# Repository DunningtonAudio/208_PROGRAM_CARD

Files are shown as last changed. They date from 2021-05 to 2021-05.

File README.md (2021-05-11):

# 208_PROGRAM_CARD
A 208 program card project

These Model 208 Program Cards are designed to interface with the “PROGRAM BOARD” edge connector of a Buchla & Associates Model 208 Stored Program Sound Source module and its reissues / compatible units. Two versions are provided, one for standard use and one with a prototyping area where additional active circuitry can be added if desired. For guidance on general use, see Allen Strange’s “Programming and Meta-Programming the Electro Organism” manual.

Beyond the settings / connections available on the original cards, the following features are provided:

* A label area on the rear of the card for easy identification of presets.
* Modulation oscillator range switch setting (where this is available on the 208 edge connector).
* An extra connection point for each of the random voltage outputs.
* Footprints for optional multi-turn trimmer potentiometers (Bourns 3266W type) in series with the sequencer voltage level settings for fine tune when programming pitched sequences.
* 5V rail brought out to the prototyping area (where this is available on the 208 edge connector)

Please read the notes before ordering or using cards.

The repository contains:

* KiCad project files, including gerber outputs
* Schematic, notes and 208 manual as PDF files

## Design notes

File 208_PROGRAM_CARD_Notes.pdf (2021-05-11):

208 Program Cards

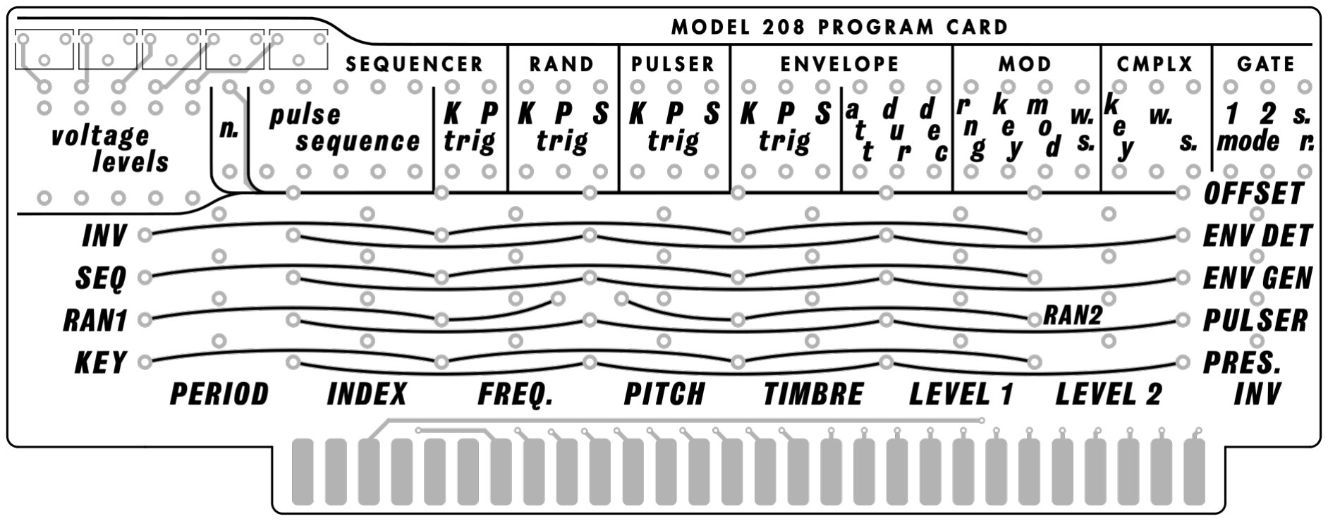
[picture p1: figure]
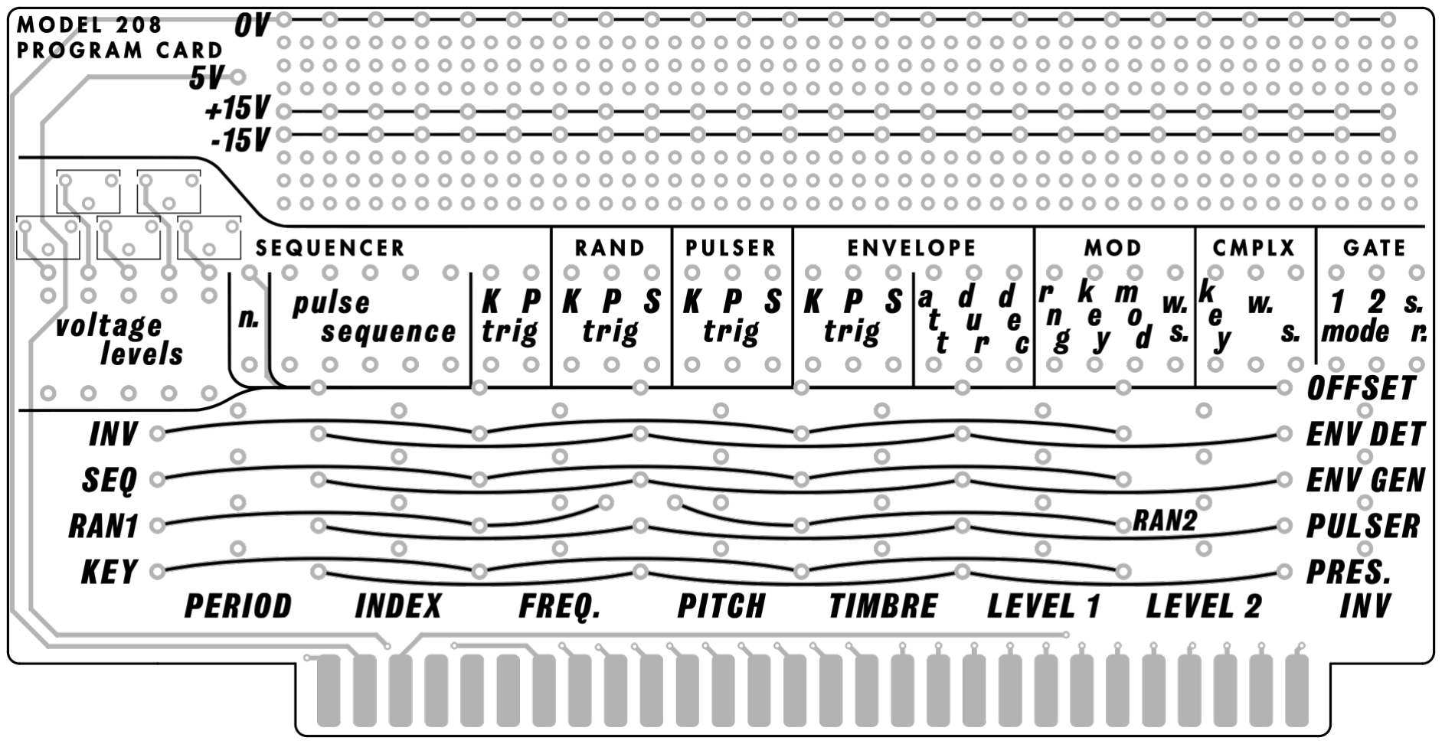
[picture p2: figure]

These Model 208 Program Cards are designed to interface with the “PROGRAM BOARD” edge connector of a Buchla & Associates Model 208 Stored Program Sound Source module and its reissues / compatible units. Two versions are provided, one for standard use and one with a prototyping area where additional active circuitry can be added if desired. For guidance on general use, see Allen Strange’s “Programming and Meta-Programming the Electro Organism” manual.

PLEASE NOTE:

**Inserting / removing program cards whilst the 208 is powered is not recommended or supported**

**The system power rails are exposed in the prototype area – use with caution to avoid damage to the power supply or 208 module**

**Not all functions provided on the cards are available on all 208 type modules**

**These cards are not compatible with Roman Filippov’s 208r rev 1**

Beyond the settings / connections available on the original cards, the following features are provided:

- A label area on the rear of the card for easy identification of presets.
- Modulation oscillator range switch setting (where this is available on the 208 edge connector).
- An extra connection point for each of the random voltage outputs.
- Footprints for optional multi-turn trimmer potentiometers (Bourns 3266W type) in series with the sequencer voltage level settings for fine tune when programming pitched sequences. Depending on whether a trimmer will be fitted, solder fixed resistors between the pads indicated:

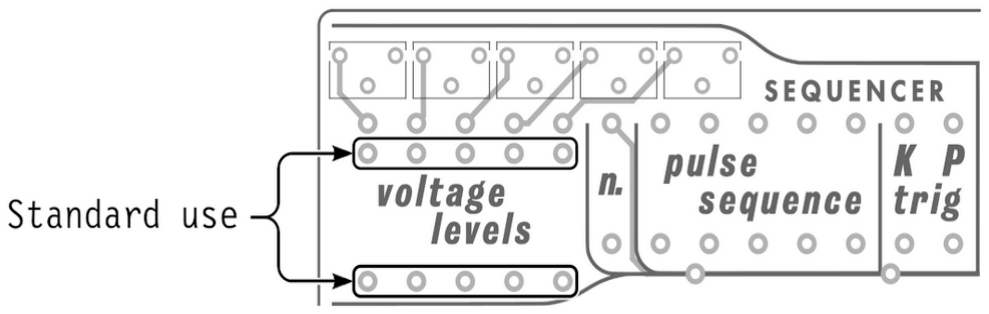
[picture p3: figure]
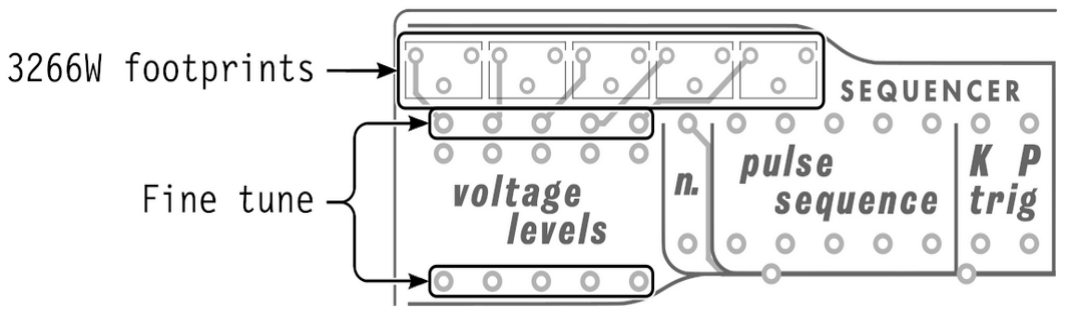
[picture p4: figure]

As the relationship between the value of resistor required and front panel setting is non linear, different value trimmers will be required depending on the desired range. A suggested approach is to take the fixed value resistor indicated for the approximate value, select a trimmer approximately 10% to 20% of this value, and reduce the value of the fixed resistor by 5% to 10% - for example for a front panel value of 4, a 300kΩ resistor would be used – this could be substituted by a 270kΩ resistor and 50kΩ trimmer to provide a reasonable range of adjustment around this value. Alternatively for a wide range of adjustment a fixed value of 120kΩ can be used with a 1MΩ trimmer, however the resolution of adjustment will be coarser at the top end than at the bottom.
- 5V rail brought out to the prototyping area (where this is available on the 208 edge connector), for easier application of microprocessors and logic in any additional circuitry.

When ordering printed circuit boards note that the cards MUST be standard 1.6mm thickness to mate correctly with the 208 edge connector. Other options such as solder mask colour and surface finish can be selected according to user preference and budget, but bevelling of the card edge (often appearing as an option under settings for “Edge Connector” or “Gold Fingers” in PCB fabricator online order pages) is highly recommended.

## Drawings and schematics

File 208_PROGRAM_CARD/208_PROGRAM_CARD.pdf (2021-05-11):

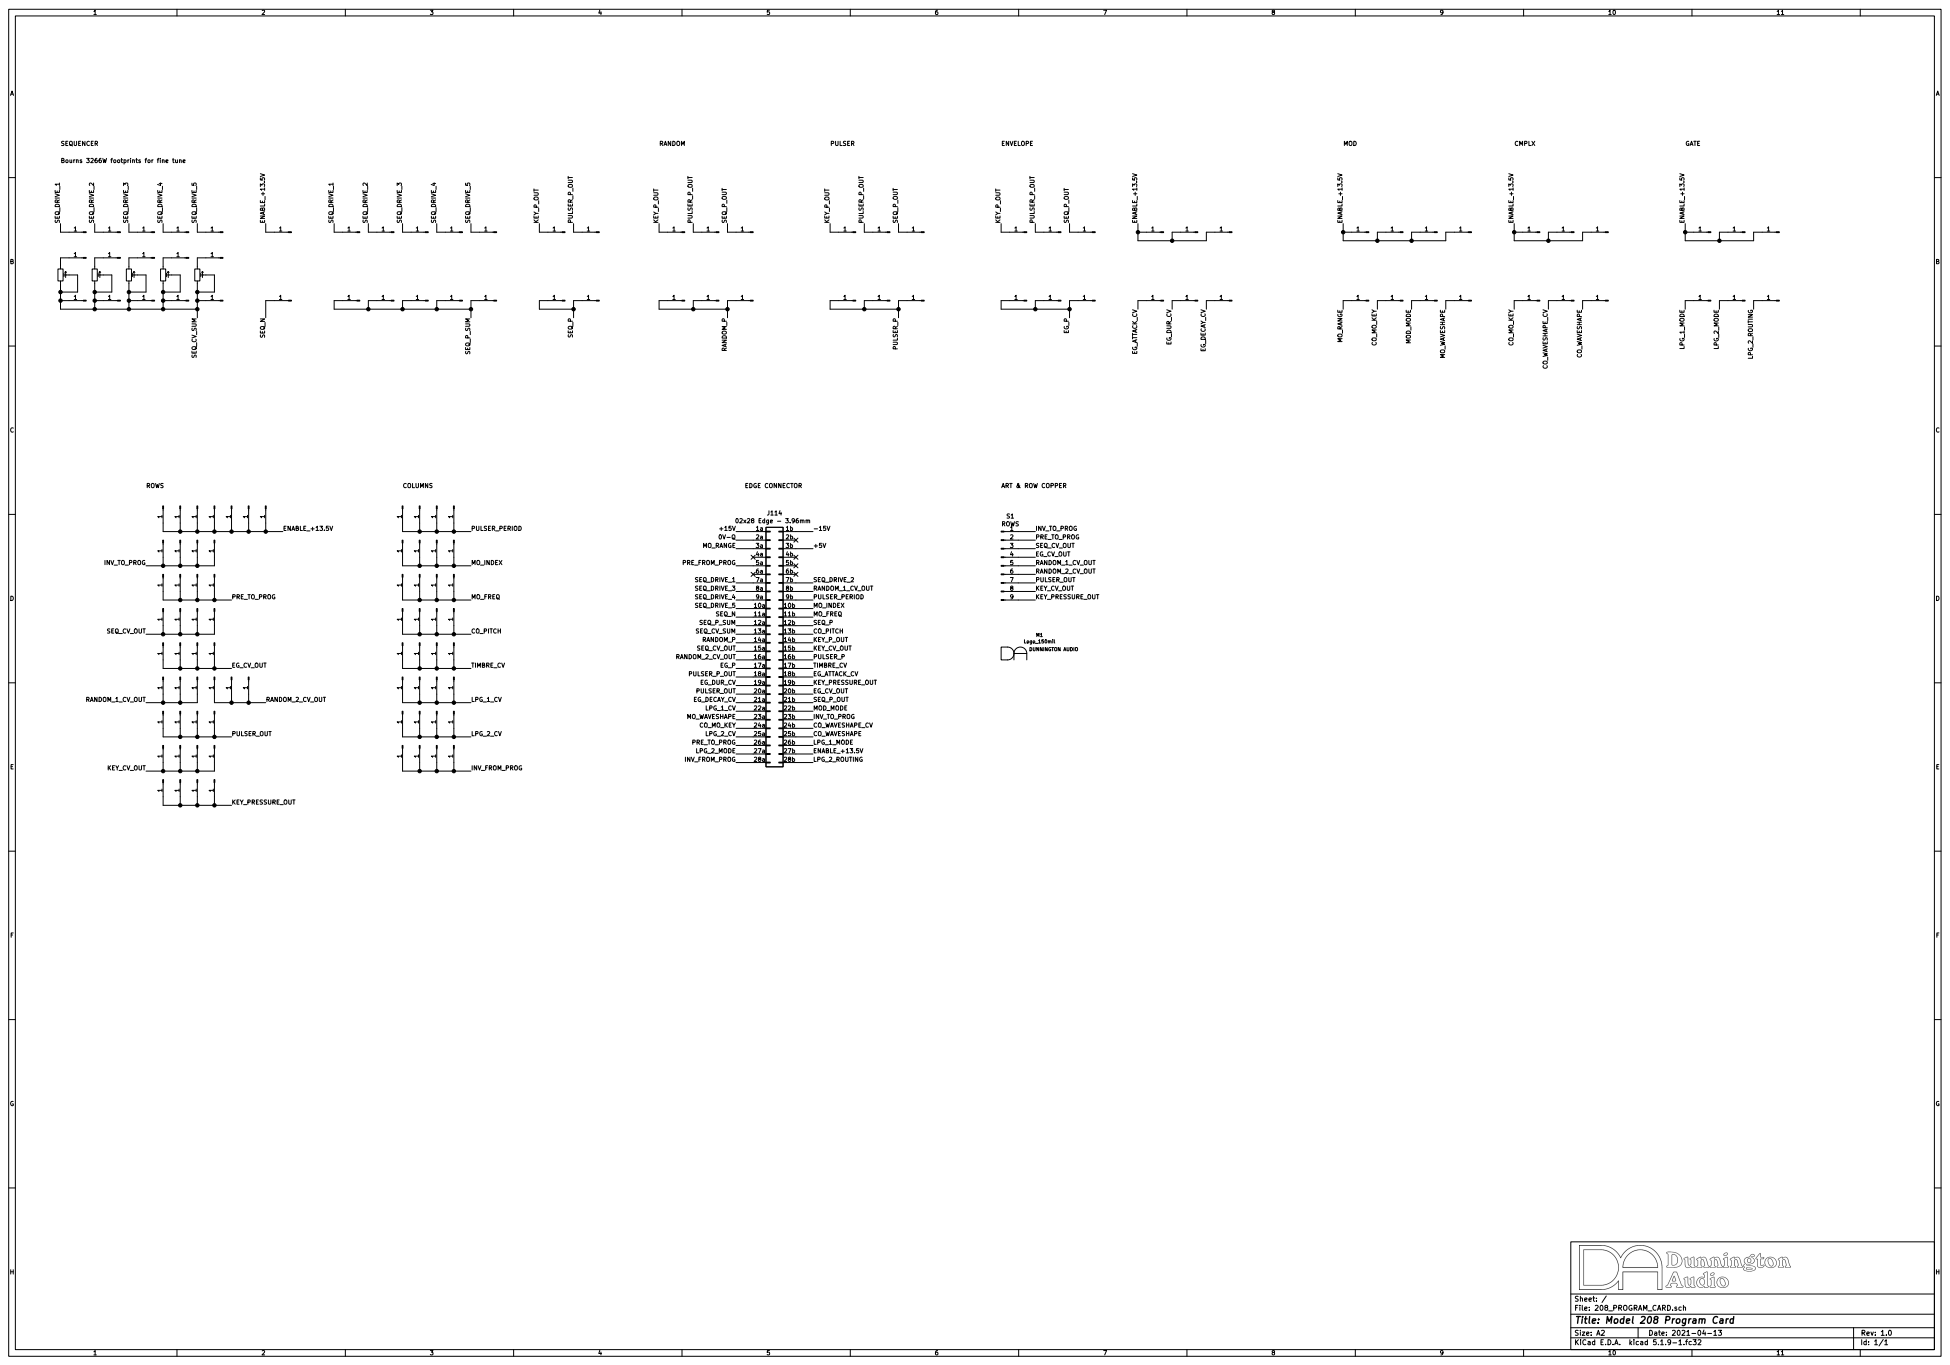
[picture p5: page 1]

File: 208_PROGRAM_CARD.sch Sheet: /
Id: 1/1 Title: Model 208 Program Card

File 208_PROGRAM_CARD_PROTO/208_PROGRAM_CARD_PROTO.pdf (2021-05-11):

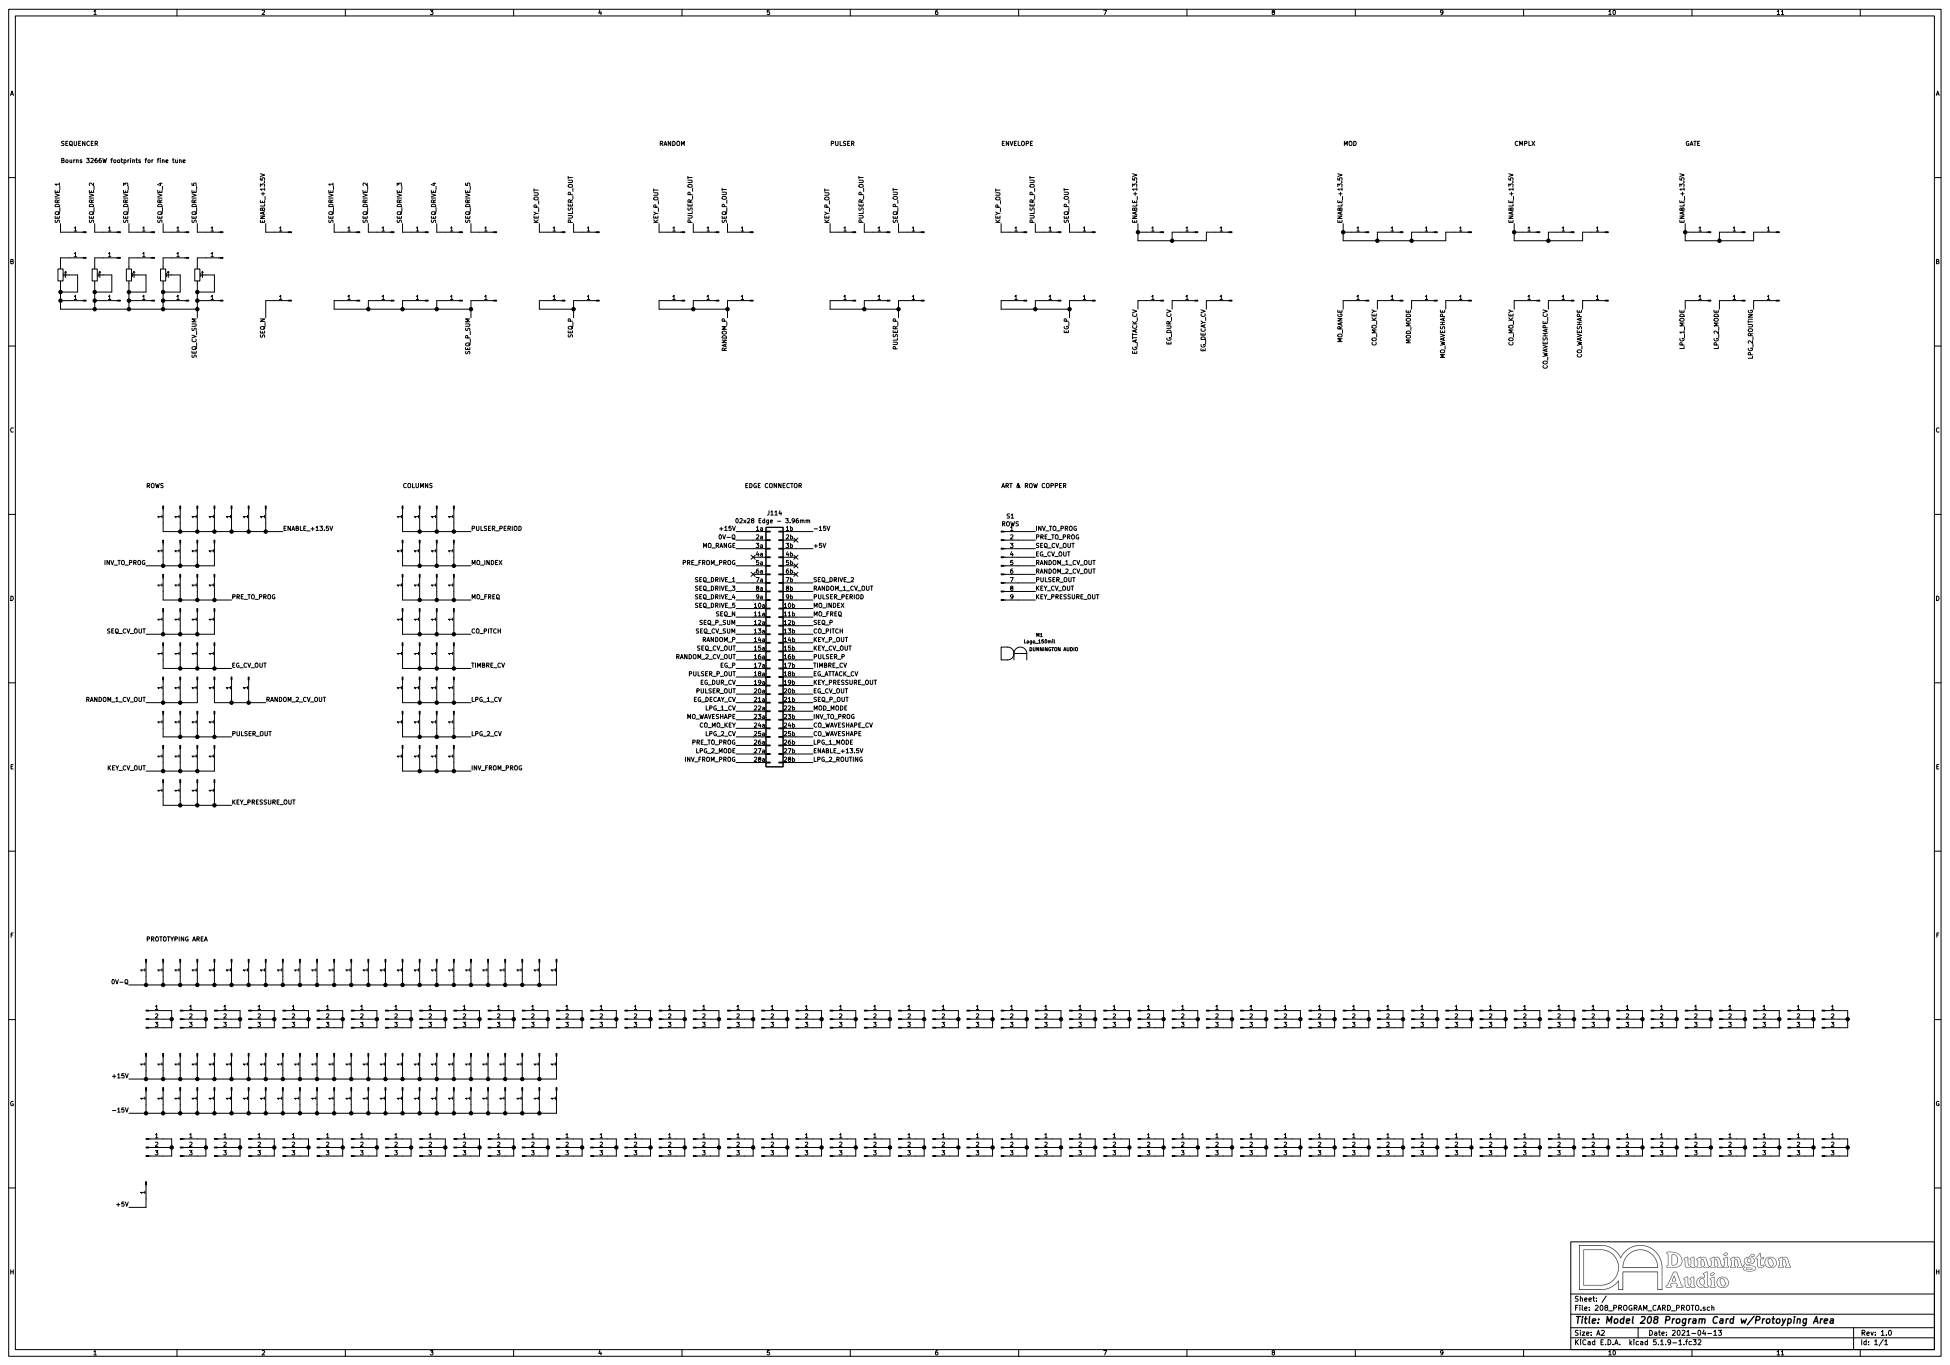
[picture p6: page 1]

Id: 1/1 Title: Model 208 Program Card w/Protoyping Area

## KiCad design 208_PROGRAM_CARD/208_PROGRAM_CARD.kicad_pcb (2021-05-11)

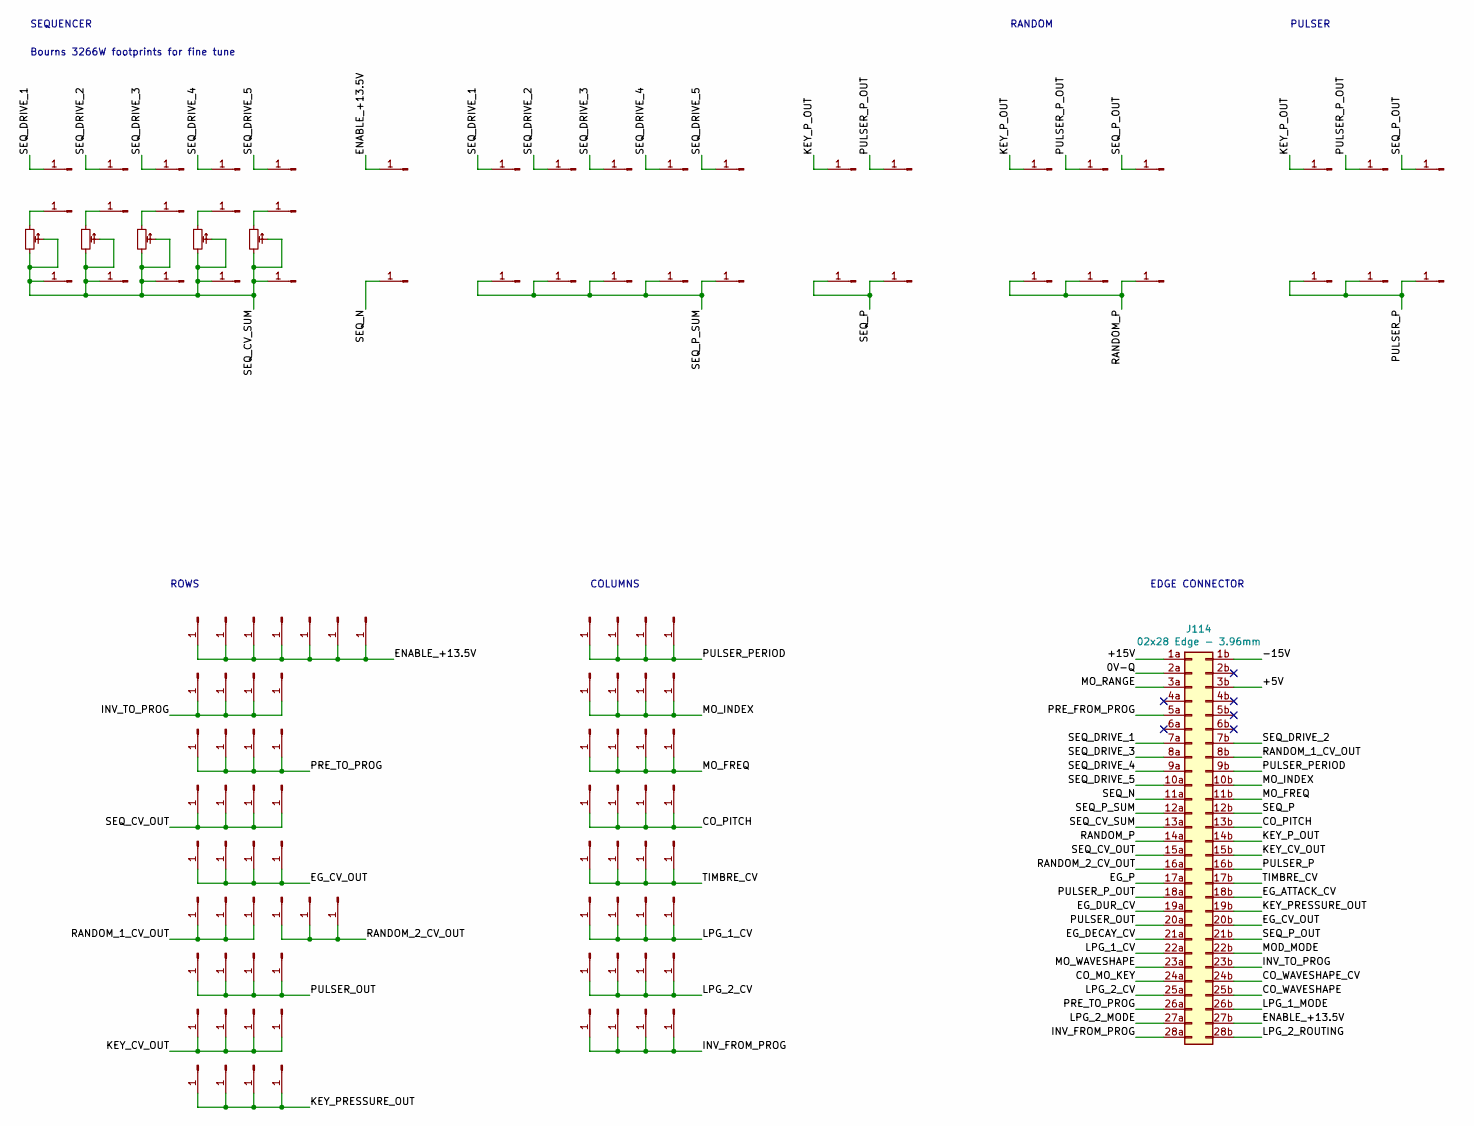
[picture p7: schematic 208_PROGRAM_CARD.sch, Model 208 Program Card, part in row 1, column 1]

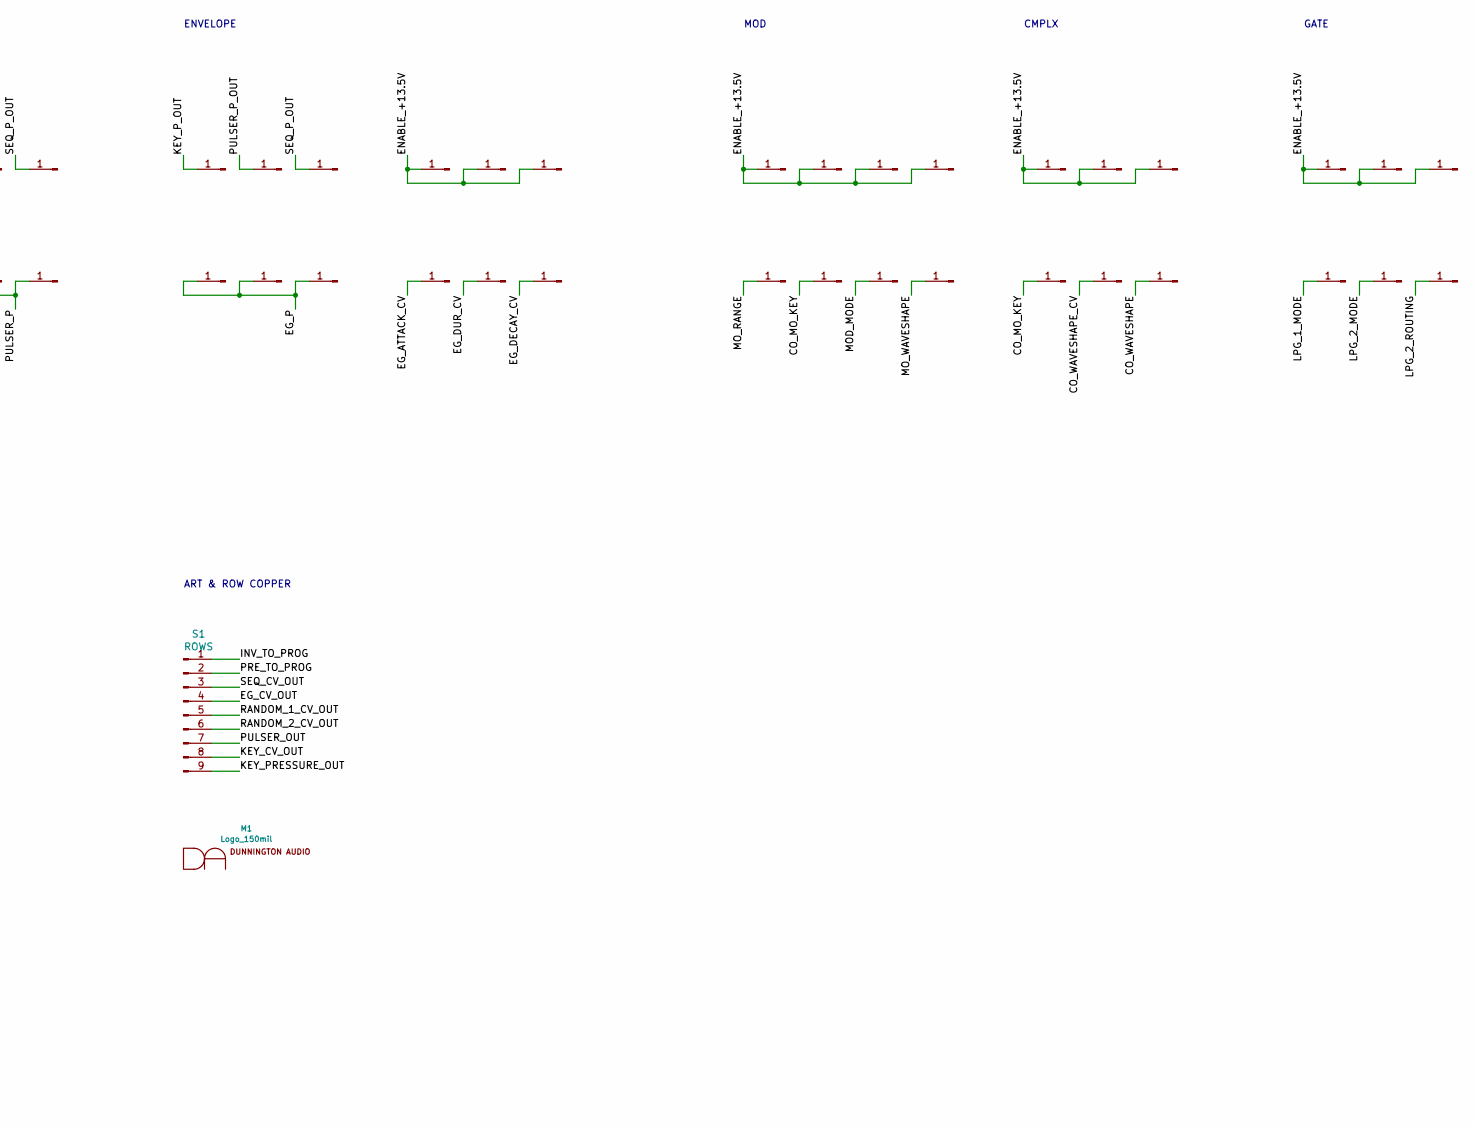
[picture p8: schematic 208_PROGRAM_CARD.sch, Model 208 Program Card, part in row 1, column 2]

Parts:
J1, J2, J3, J4, J5, J6, J7, J8, J9, J10, J11, J12, J13, J14, J15, J16, J17, J18, J19, J20, J21, J22, J23, J24, J25, J26, J27, J28, J29, J30, J31, J32, J33, J34, J35, J36, J37, J38, J39, J40, J41, J42, J43, J44, J45, J46, J47, J48, J49, J50, J51, J52, J53, J54, J55, J56, J57, J58, J59, J60, J61, J62, J63, J64, J65, J66, J67, J68, J69, J70, J71, J72, J73, J74, J75, J76, J77, J78, J79, J80, J81, J82, J83, J84, J85, J86, J87, J88, J89, J90, J91, J92, J93, J94, J95, J96, J97, J98, J99, J100, J101, J102, J103, J104, J105, J106, J107, J108, J109, J110, J111, J112, J113, J115, J116, J117, J118, J119, J120, J121, J122, J123, J124, J125, J126, J127, J128, J129, J130, J131, J132, J133, J134, J135, J136, J137, J138, J139, J140, J141, J142, J143, J144, J354, J355, J356, J357, J358: Pad; SolderWirePad_1x01_Drill0.9mm
J114: 02x28 Edge - 3.96mm; 305-056-500-502_Mating_Edge
M1: Logo_150mil
S1: ROWS; 208_PROGRAM_CARD
TR1, TR2, TR3, TR4, TR5: TRIM; Potentiometer_Bourns_3266W_Vertical

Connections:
/0V-Q: J114.2a
/+5V: J114.3b
/+15V: J114.1a
/-15V: J114.1b
/CO_MO_KEY: J62.1, J65.1, J114.24a
/CO_PITCH: J102.1, J103.1, J104.1, J105.1, J114.13b
/CO_WAVESHAPE: J67.1, J114.25b
/CO_WAVESHAPE_CV: J66.1, J114.24b
/EG_ATTACK_CV: J58.1, J114.18b
/EG_CV_OUT: J106.1, J107.1, J108.1, J109.1, J114.20b, S1.4
/EG_DECAY_CV: J60.1, J114.21a
/EG_DUR_CV: J59.1, J114.19a
/EG_P: J55.1, J56.1, J57.1, J114.17a
/ENABLE_+13.5V: J6.1, J23.1, J24.1, J25.1, J26.1, J27.1, J28.1, J29.1, J30.1, J31.1, J32.1, J33.1, J34.1, J35.1, J71.1, J72.1, J73.1, J74.1, J75.1, J76.1, J77.1, J114.27b
/INV_FROM_PROG: J114.28a, J137.1, J138.1, J139.1, J140.1
/INV_TO_PROG: J82.1, J83.1, J84.1, J85.1, J114.23b, S1.1
/KEY_CV_OUT: J114.15b, J133.1, J134.1, J135.1, J136.1, S1.8
/KEY_PRESSURE_OUT: J114.19b, J141.1, J142.1, J143.1, J144.1, S1.9
/KEY_P_OUT: J12.1, J14.1, J17.1, J20.1, J114.14b
/LPG_1_CV: J114.22a, J121.1, J122.1, J123.1, J124.1
/LPG_1_MODE: J68.1, J114.26b
/LPG_2_CV: J114.25a, J129.1, J130.1, J131.1, J132.1
/LPG_2_MODE: J69.1, J114.27a
/LPG_2_ROUTING: J70.1, J114.28b
/MOD_MODE: J63.1, J114.22b
/MO_FREQ: J94.1, J95.1, J96.1, J97.1, J114.11b
/MO_INDEX: J86.1, J87.1, J88.1, J89.1, J114.10b
/MO_RANGE: J61.1, J114.3a
/MO_WAVESHAPE: J64.1, J114.23a
/PRE_FROM_PROG: J114.5a
/PRE_TO_PROG: J90.1, J91.1, J92.1, J93.1, J114.26a, S1.2
/PULSER_OUT: J114.20a, J125.1, J126.1, J127.1, J128.1, S1.7
/PULSER_P: J52.1, J53.1, J54.1, J114.16b
/PULSER_PERIOD: J78.1, J79.1, J80.1, J81.1, J114.9b
/PULSER_P_OUT: J13.1, J15.1, J18.1, J21.1, J114.18a
/RANDOM_1_CV_OUT: J114.8b, J115.1, J116.1, J117.1, S1.5
/RANDOM_2_CV_OUT: J114.16a, J118.1, J119.1, J120.1, S1.6
/RANDOM_P: J49.1, J50.1, J51.1, J114.14a
/SEQ_CV_OUT: J98.1, J99.1, J100.1, J101.1, J114.15a, S1.3
/SEQ_CV_SUM: J36.1, J37.1, J38.1, J39.1, J40.1, J114.13a, TR1.1, TR1.2, TR2.1, TR2.2, TR3.1, TR3.2, TR4.1, TR4.2, TR5.1, TR5.2
/SEQ_DRIVE_1: J1.1, J7.1, J114.7a
/SEQ_DRIVE_2: J2.1, J8.1, J114.7b
/SEQ_DRIVE_3: J3.1, J9.1, J114.8a
/SEQ_DRIVE_4: J4.1, J10.1, J114.9a
/SEQ_DRIVE_5: J5.1, J11.1, J114.10a
/SEQ_N: J41.1, J114.11a
/SEQ_P: J47.1, J48.1, J114.12b
/SEQ_P_OUT: J16.1, J19.1, J22.1, J114.21b
/SEQ_P_SUM: J42.1, J43.1, J44.1, J45.1, J46.1, J114.12a
/TIMBRE_CV: J110.1, J111.1, J112.1, J113.1, J114.17b
unnamed: J354.1, TR1.3
unnamed: J355.1, TR2.3
unnamed: J356.1, TR3.3
unnamed: J357.1, TR4.3
unnamed: J358.1, TR5.3

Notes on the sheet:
ROWS
COLUMNS
EDGE CONNECTOR
SEQUENCER
RANDOM
PULSER
ENVELOPE
MOD
CMPLX
GATE
ART & ROW COPPER
Bourns 3266W footprints for fine tune

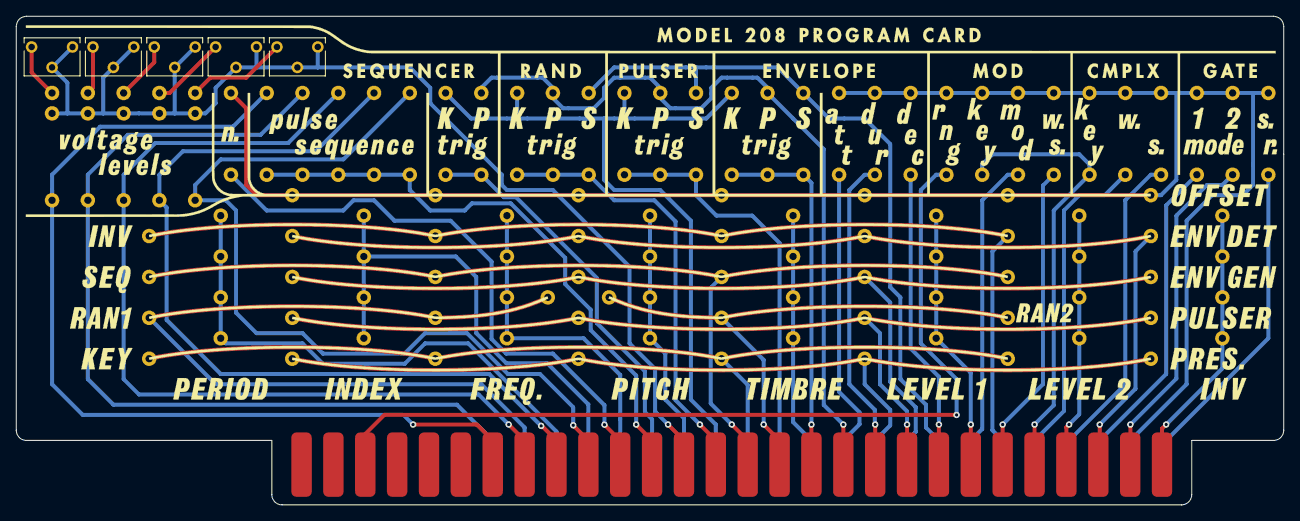
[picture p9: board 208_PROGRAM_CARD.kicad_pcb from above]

Board: 2 copper layers, 157.5 x 60.7 mm, 156 parts (1 on the bottom side), 50 nets.

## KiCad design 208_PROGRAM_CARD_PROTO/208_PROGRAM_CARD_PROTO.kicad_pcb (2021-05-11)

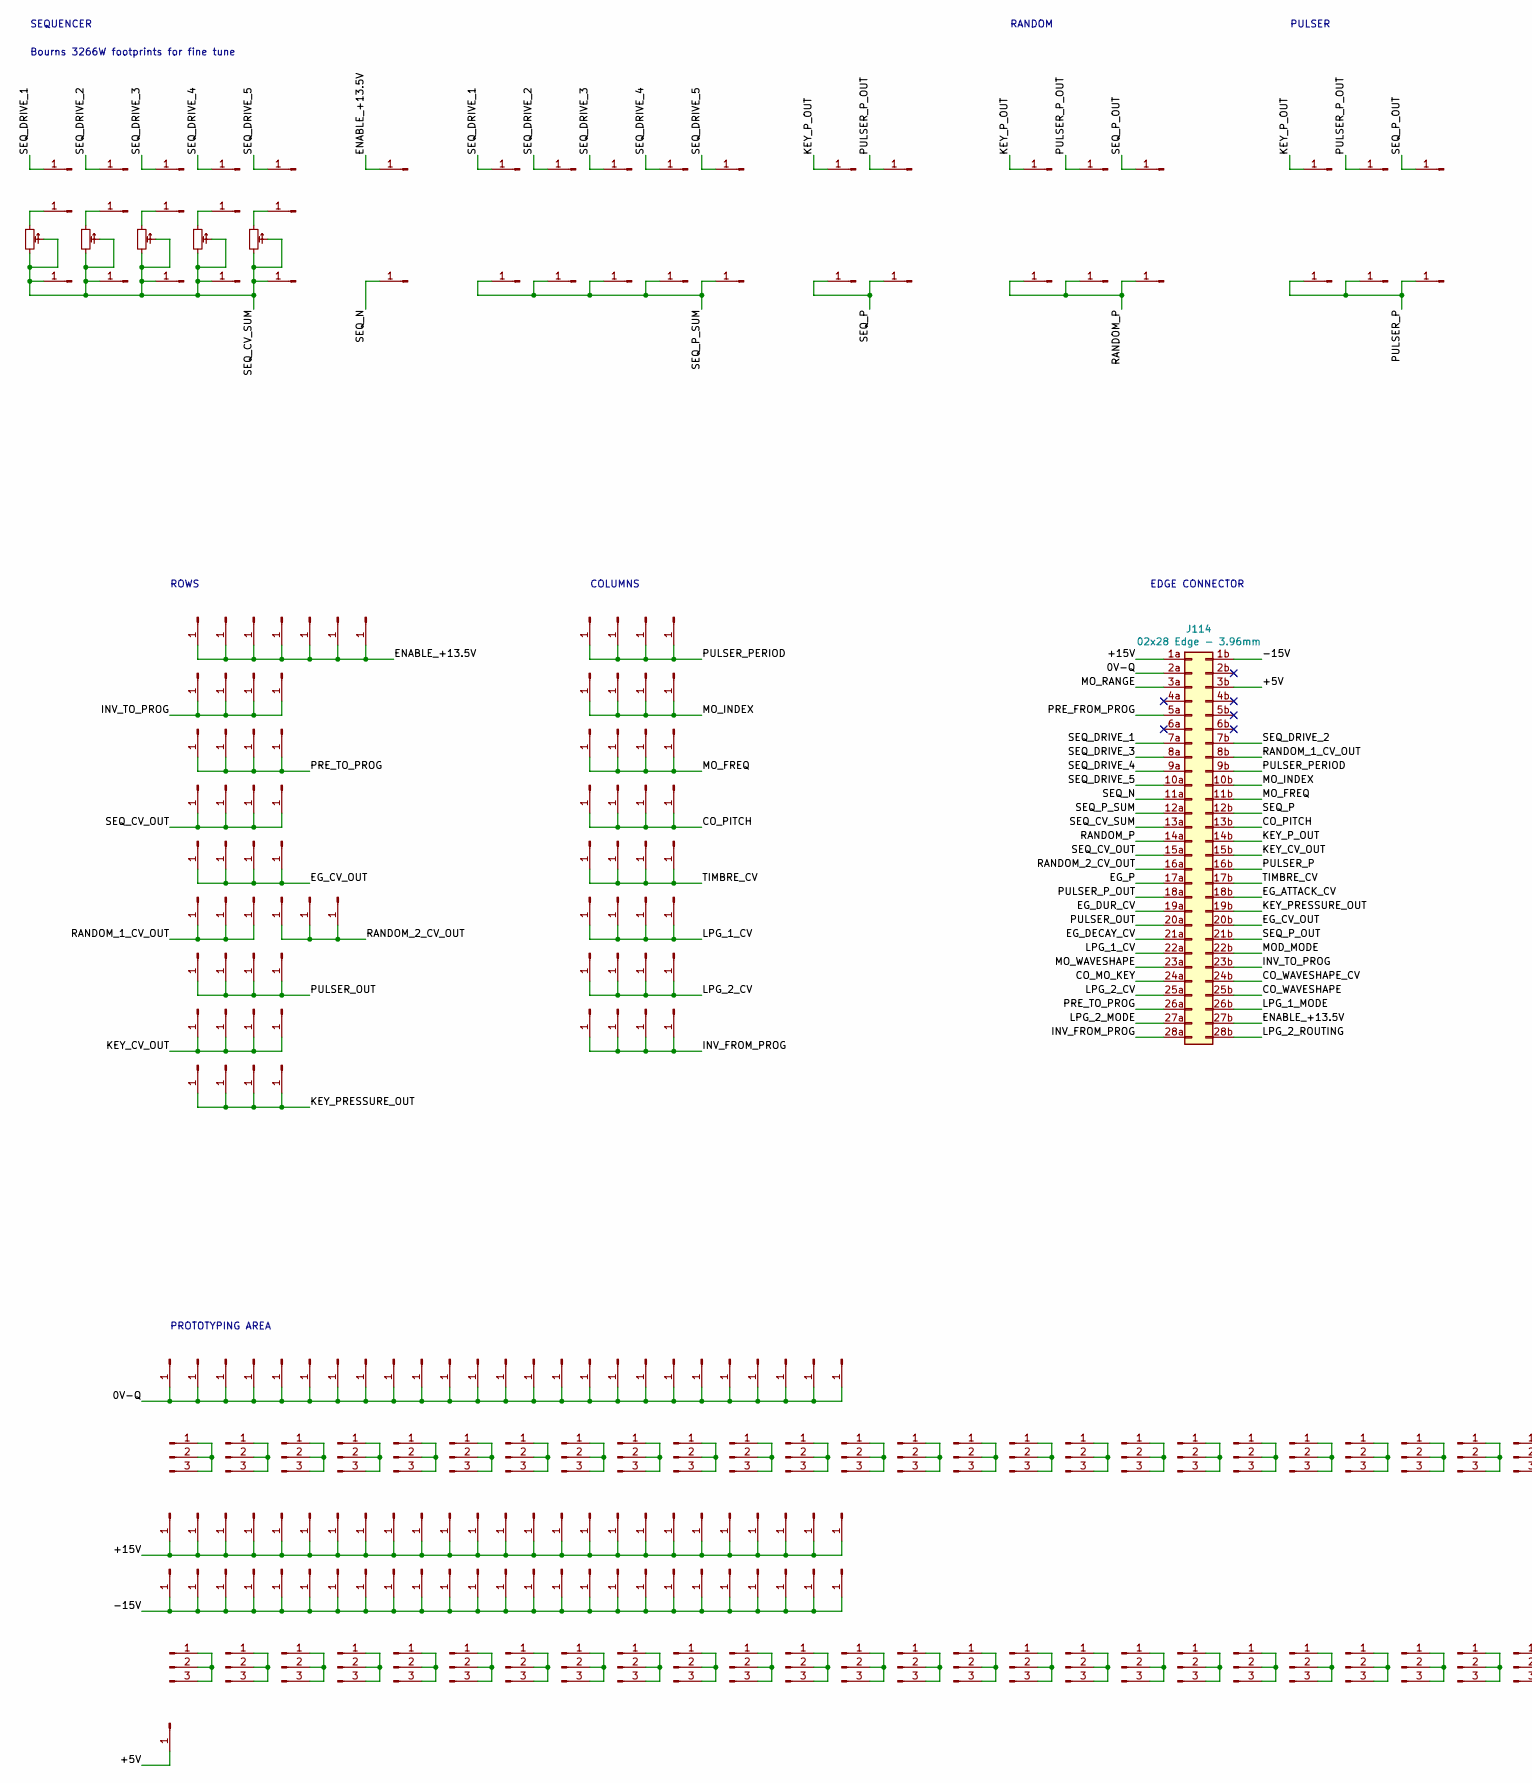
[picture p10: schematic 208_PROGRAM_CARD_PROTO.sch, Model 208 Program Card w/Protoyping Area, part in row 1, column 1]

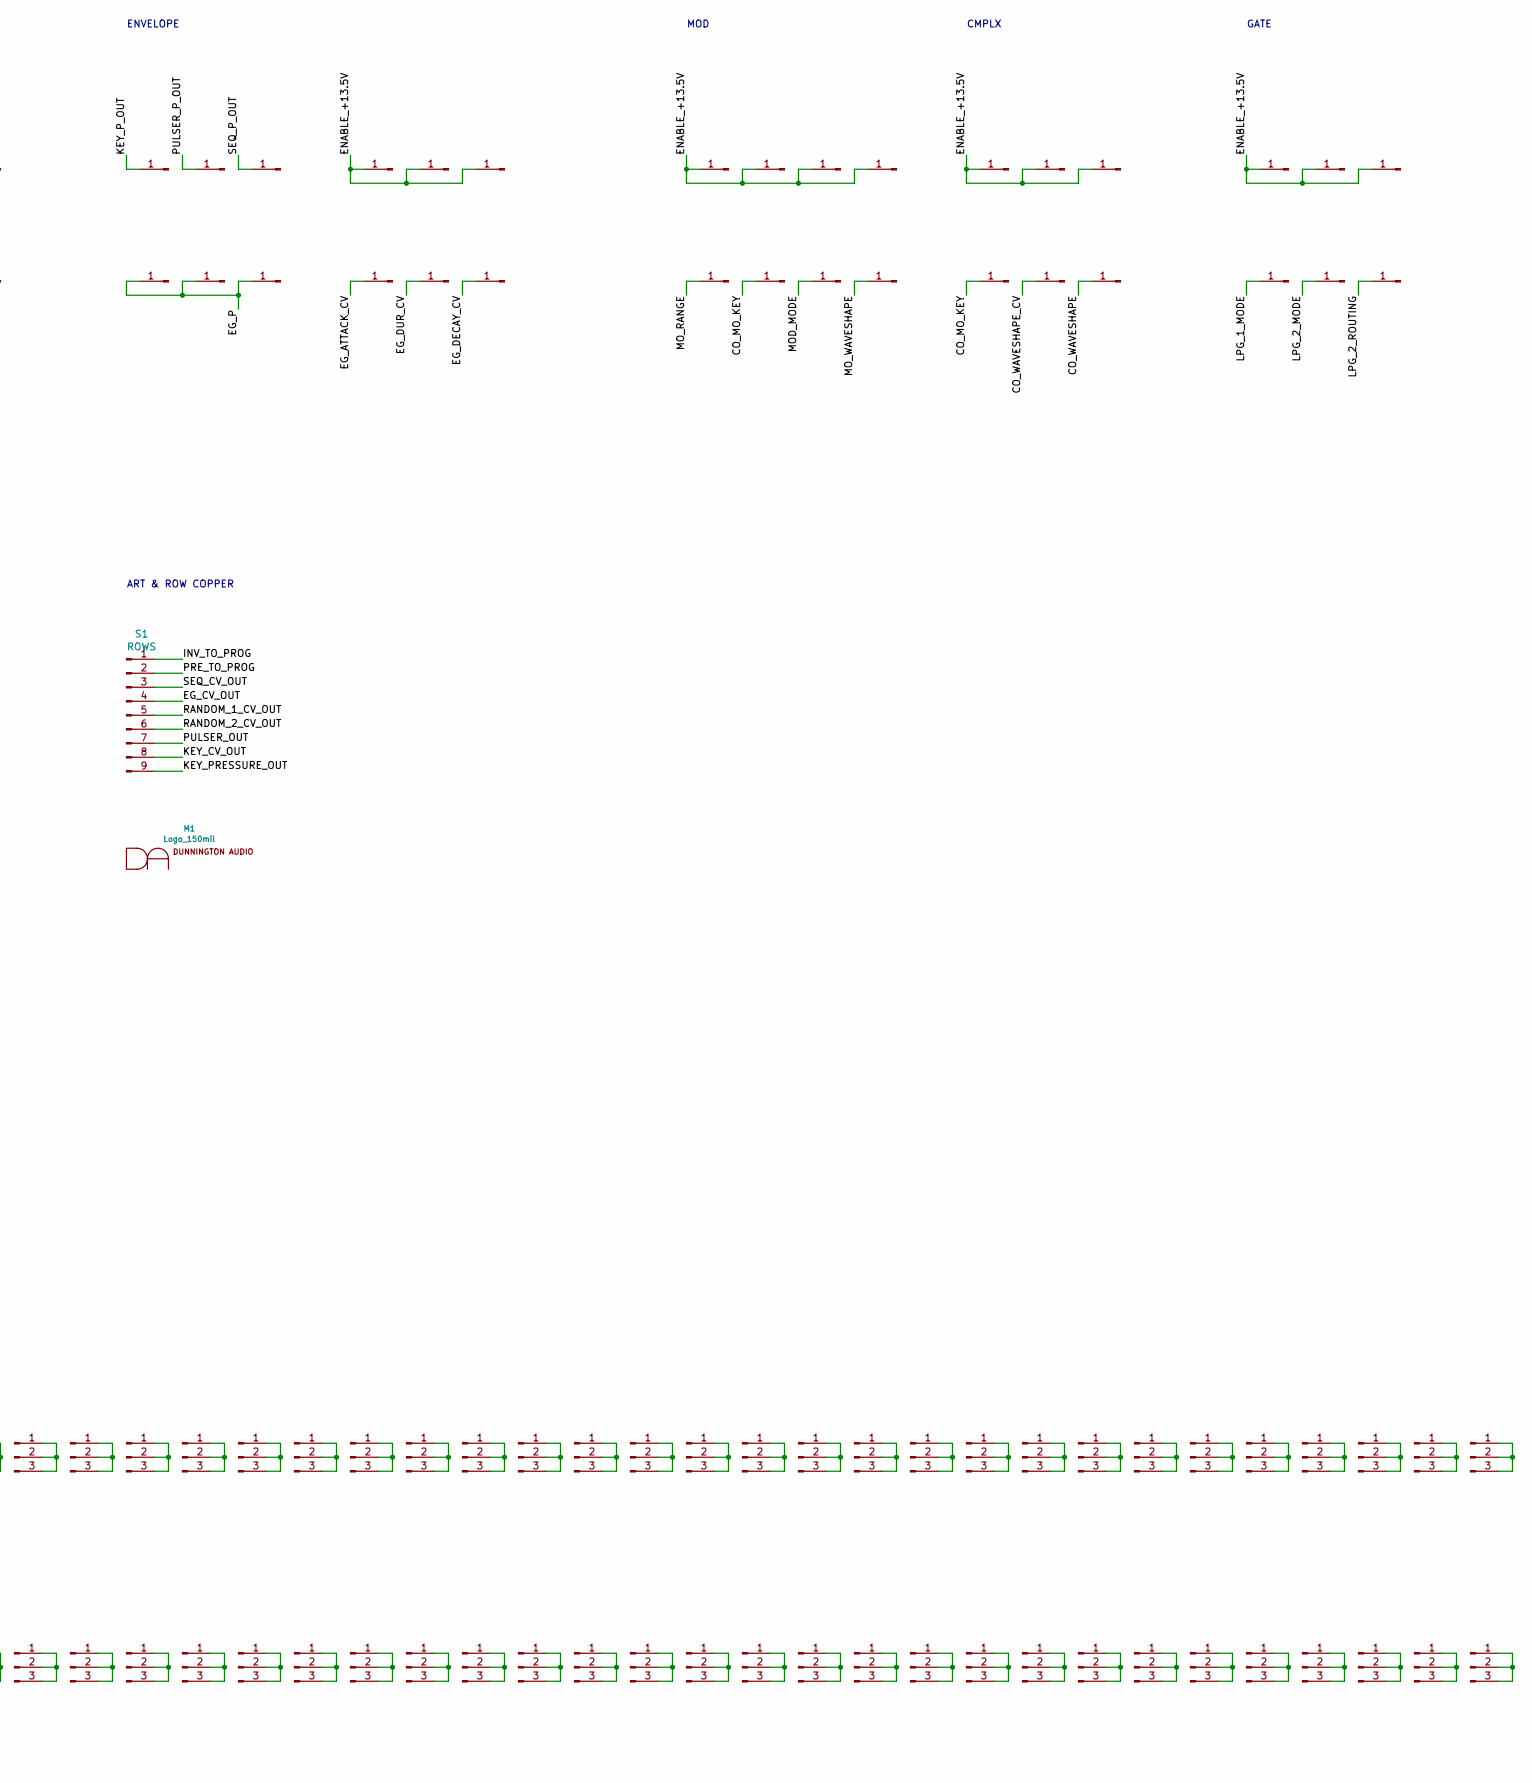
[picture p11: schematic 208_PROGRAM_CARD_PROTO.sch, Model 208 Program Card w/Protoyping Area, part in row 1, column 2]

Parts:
J1, J2, J3, J4, J5, J6, J7, J8, J9, J10, J11, J12, J13, J14, J15, J16, J17, J18, J19, J20, J21, J22, J23, J24, J25, J26, J27, J28, J29, J30, J31, J32, J33, J34, J35, J36, J37, J38, J39, J40, J41, J42, J43, J44, J45, J46, J47, J48, J49, J50, J51, J52, J53, J54, J55, J56, J57, J58, J59, J60, J61, J62, J63, J64, J65, J66, J67, J68, J69, J70, J71, J72, J73, J74, J75, J76, J77, J78, J79, J80, J81, J82, J83, J84, J85, J86, J87, J88, J89, J90, J91, J92, J93, J94, J95, J96, J97, J98, J99, J100, J101, J102, J103, J104, J105, J106, J107, J108, J109, J110, J111, J112, J113, J115, J116, J117, J118, J119, J120, J121, J122, J123, J124, J125, J126, J127, J128, J129, J130, J131, J132, J133, J134, J135, J136, J137, J138, J139, J140, J141, J142, J143, J144, J145, J146, J147, J148, J149, J150, J151, J152, J153, J154, J155, J156, J157, J158, J159, J160, J161, J162, J163, J164, J165, J166, J167, J168, J169, J233, J234, J235, J236, J237, J238, J239, J240, J241, J242, J243, J244, J245, J246, J247, J248, J249, J250, J251, J252, J253, J254, J255, J256, J257, J265, J266, J267, J268, J269, J270, J271, J272, J273, J274, J275, J276, J277, J278, J279, J280, J281, J282, J283, J284, J285, J286, J287, J288, J289, J353, J354, J355, J356, J357, J358: Pad; SolderWirePad_1x01_Drill0.9mm
J114: 02x28 Edge - 3.96mm; 305-056-500-502_Mating_Edge
J177, J178, J179, J180, J181, J182, J183, J184, J185, J186, J187, J188, J189, J190, J191, J192, J193, J194, J195, J196, J197, J198, J199, J200, J201, J202, J203, J204, J205, J206, J207, J208, J209, J210, J211, J212, J213, J214, J215, J216, J217, J218, J219, J220, J221, J222, J223, J224, J225, J226, J297, J298, J299, J300, J301, J302, J303, J304, J305, J306, J307, J308, J309, J310, J311, J312, J313, J314, J315, J316, J317, J318, J319, J320, J321, J322, J323, J324, J325, J326, J327, J328, J329, J330, J331, J332, J333, J334, J335, J336, J337, J338, J339, J340, J341, J342, J343, J344, J345, J346: Muck Pads
M1: Logo_150mil
S1: ROWS; 208_PROGRAM_CARD_PROTO
TR1, TR2, TR3, TR4, TR5: TRIM; Potentiometer_Bourns_3266W_Vertical

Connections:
/0V-Q: J114.2a, J145.1, J146.1, J147.1, J148.1, J149.1, J150.1, J151.1, J152.1, J153.1, J154.1, J155.1, J156.1, J157.1, J158.1, J159.1, J160.1, J161.1, J162.1, J163.1, J164.1, J165.1, J166.1, J167.1, J168.1, J169.1
/+5V: J114.3b, J353.1
/+15V: J114.1a, J233.1, J234.1, J235.1, J236.1, J237.1, J238.1, J239.1, J240.1, J241.1, J242.1, J243.1, J244.1, J245.1, J246.1, J247.1, J248.1, J249.1, J250.1, J251.1, J252.1, J253.1, J254.1, J255.1, J256.1, J257.1
/-15V: J114.1b, J265.1, J266.1, J267.1, J268.1, J269.1, J270.1, J271.1, J272.1, J273.1, J274.1, J275.1, J276.1, J277.1, J278.1, J279.1, J280.1, J281.1, J282.1, J283.1, J284.1, J285.1, J286.1, J287.1, J288.1, J289.1
/CO_MO_KEY: J62.1, J65.1, J114.24a
/CO_PITCH: J102.1, J103.1, J104.1, J105.1, J114.13b
/CO_WAVESHAPE: J67.1, J114.25b
/CO_WAVESHAPE_CV: J66.1, J114.24b
/EG_ATTACK_CV: J58.1, J114.18b
/EG_CV_OUT: J106.1, J107.1, J108.1, J109.1, J114.20b, S1.4
/EG_DECAY_CV: J60.1, J114.21a
/EG_DUR_CV: J59.1, J114.19a
/EG_P: J55.1, J56.1, J57.1, J114.17a
/ENABLE_+13.5V: J6.1, J23.1, J24.1, J25.1, J26.1, J27.1, J28.1, J29.1, J30.1, J31.1, J32.1, J33.1, J34.1, J35.1, J71.1, J72.1, J73.1, J74.1, J75.1, J76.1, J77.1, J114.27b
/INV_FROM_PROG: J114.28a, J137.1, J138.1, J139.1, J140.1
/INV_TO_PROG: J82.1, J83.1, J84.1, J85.1, J114.23b, S1.1
/KEY_CV_OUT: J114.15b, J133.1, J134.1, J135.1, J136.1, S1.8
/KEY_PRESSURE_OUT: J114.19b, J141.1, J142.1, J143.1, J144.1, S1.9
/KEY_P_OUT: J12.1, J14.1, J17.1, J20.1, J114.14b
/LPG_1_CV: J114.22a, J121.1, J122.1, J123.1, J124.1
/LPG_1_MODE: J68.1, J114.26b
/LPG_2_CV: J114.25a, J129.1, J130.1, J131.1, J132.1
/LPG_2_MODE: J69.1, J114.27a
/LPG_2_ROUTING: J70.1, J114.28b
/MOD_MODE: J63.1, J114.22b
/MO_FREQ: J94.1, J95.1, J96.1, J97.1, J114.11b
/MO_INDEX: J86.1, J87.1, J88.1, J89.1, J114.10b
/MO_RANGE: J61.1, J114.3a
/MO_WAVESHAPE: J64.1, J114.23a
/PRE_FROM_PROG: J114.5a
/PRE_TO_PROG: J90.1, J91.1, J92.1, J93.1, J114.26a, S1.2
/PULSER_OUT: J114.20a, J125.1, J126.1, J127.1, J128.1, S1.7
/PULSER_P: J52.1, J53.1, J54.1, J114.16b
/PULSER_PERIOD: J78.1, J79.1, J80.1, J81.1, J114.9b
/PULSER_P_OUT: J13.1, J15.1, J18.1, J21.1, J114.18a
/RANDOM_1_CV_OUT: J114.8b, J115.1, J116.1, J117.1, S1.5
/RANDOM_2_CV_OUT: J114.16a, J118.1, J119.1, J120.1, S1.6
/RANDOM_P: J49.1, J50.1, J51.1, J114.14a
/SEQ_CV_OUT: J98.1, J99.1, J100.1, J101.1, J114.15a, S1.3
/SEQ_CV_SUM: J36.1, J37.1, J38.1, J39.1, J40.1, J114.13a, TR1.1, TR1.2, TR2.1, TR2.2, TR3.1, TR3.2, TR4.1, TR4.2, TR5.1, TR5.2
/SEQ_DRIVE_1: J1.1, J7.1, J114.7a
/SEQ_DRIVE_2: J2.1, J8.1, J114.7b
/SEQ_DRIVE_3: J3.1, J9.1, J114.8a
/SEQ_DRIVE_4: J4.1, J10.1, J114.9a
/SEQ_DRIVE_5: J5.1, J11.1, J114.10a
/SEQ_N: J41.1, J114.11a
/SEQ_P: J47.1, J48.1, J114.12b
/SEQ_P_OUT: J16.1, J19.1, J22.1, J114.21b
/SEQ_P_SUM: J42.1, J43.1, J44.1, J45.1, J46.1, J114.12a
/TIMBRE_CV: J110.1, J111.1, J112.1, J113.1, J114.17b
unnamed: J177.1, J177.2, J177.3
unnamed: J178.1, J178.2, J178.3
unnamed: J179.1, J179.2, J179.3
unnamed: J180.1, J180.2, J180.3
unnamed: J181.1, J181.2, J181.3
unnamed: J182.1, J182.2, J182.3
unnamed: J183.1, J183.2, J183.3
unnamed: J184.1, J184.2, J184.3
unnamed: J185.1, J185.2, J185.3
unnamed: J186.1, J186.2, J186.3
unnamed: J187.1, J187.2, J187.3
unnamed: J188.1, J188.2, J188.3
unnamed: J189.1, J189.2, J189.3
unnamed: J190.1, J190.2, J190.3
unnamed: J191.1, J191.2, J191.3
unnamed: J192.1, J192.2, J192.3
unnamed: J193.1, J193.2, J193.3
unnamed: J194.1, J194.2, J194.3
unnamed: J195.1, J195.2, J195.3
unnamed: J196.1, J196.2, J196.3
unnamed: J197.1, J197.2, J197.3
unnamed: J198.1, J198.2, J198.3
unnamed: J199.1, J199.2, J199.3
unnamed: J200.1, J200.2, J200.3
unnamed: J201.1, J201.2, J201.3
unnamed: J202.1, J202.2, J202.3
unnamed: J203.1, J203.2, J203.3
unnamed: J204.1, J204.2, J204.3
unnamed: J205.1, J205.2, J205.3
unnamed: J206.1, J206.2, J206.3
unnamed: J207.1, J207.2, J207.3
unnamed: J208.1, J208.2, J208.3
unnamed: J209.1, J209.2, J209.3
unnamed: J210.1, J210.2, J210.3
unnamed: J211.1, J211.2, J211.3
unnamed: J212.1, J212.2, J212.3
unnamed: J213.1, J213.2, J213.3
unnamed: J214.1, J214.2, J214.3
unnamed: J215.1, J215.2, J215.3
unnamed: J216.1, J216.2, J216.3
unnamed: J217.1, J217.2, J217.3
unnamed: J218.1, J218.2, J218.3
unnamed: J219.1, J219.2, J219.3
unnamed: J220.1, J220.2, J220.3
unnamed: J221.1, J221.2, J221.3
unnamed: J222.1, J222.2, J222.3
unnamed: J223.1, J223.2, J223.3
unnamed: J224.1, J224.2, J224.3
unnamed: J225.1, J225.2, J225.3
unnamed: J226.1, J226.2, J226.3
unnamed: J297.1, J297.2, J297.3
unnamed: J298.1, J298.2, J298.3
unnamed: J299.1, J299.2, J299.3
unnamed: J300.1, J300.2, J300.3
unnamed: J301.1, J301.2, J301.3
unnamed: J302.1, J302.2, J302.3
unnamed: J303.1, J303.2, J303.3
unnamed: J304.1, J304.2, J304.3
unnamed: J305.1, J305.2, J305.3
unnamed: J306.1, J306.2, J306.3
unnamed: J307.1, J307.2, J307.3
unnamed: J308.1, J308.2, J308.3
unnamed: J309.1, J309.2, J309.3
unnamed: J310.1, J310.2, J310.3
unnamed: J311.1, J311.2, J311.3
unnamed: J312.1, J312.2, J312.3
unnamed: J313.1, J313.2, J313.3
unnamed: J314.1, J314.2, J314.3
unnamed: J315.1, J315.2, J315.3
unnamed: J316.1, J316.2, J316.3
unnamed: J317.1, J317.2, J317.3
unnamed: J318.1, J318.2, J318.3
unnamed: J319.1, J319.2, J319.3
unnamed: J320.1, J320.2, J320.3
unnamed: J321.1, J321.2, J321.3
unnamed: J322.1, J322.2, J322.3
unnamed: J323.1, J323.2, J323.3
unnamed: J324.1, J324.2, J324.3
unnamed: J325.1, J325.2, J325.3
unnamed: J326.1, J326.2, J326.3
unnamed: J327.1, J327.2, J327.3
unnamed: J328.1, J328.2, J328.3
unnamed: J329.1, J329.2, J329.3
unnamed: J330.1, J330.2, J330.3
unnamed: J331.1, J331.2, J331.3
unnamed: J332.1, J332.2, J332.3
unnamed: J333.1, J333.2, J333.3
unnamed: J334.1, J334.2, J334.3
unnamed: J335.1, J335.2, J335.3
unnamed: J336.1, J336.2, J336.3
unnamed: J337.1, J337.2, J337.3
unnamed: J338.1, J338.2, J338.3
unnamed: J339.1, J339.2, J339.3
unnamed: J340.1, J340.2, J340.3
unnamed: J341.1, J341.2, J341.3
unnamed: J342.1, J342.2, J342.3
unnamed: J343.1, J343.2, J343.3
unnamed: J344.1, J344.2, J344.3
unnamed: J345.1, J345.2, J345.3
unnamed: J346.1, J346.2, J346.3
unnamed: J354.1, TR1.3
unnamed: J355.1, TR2.3
unnamed: J356.1, TR3.3
unnamed: J357.1, TR4.3
unnamed: J358.1, TR5.3

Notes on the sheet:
ROWS
COLUMNS
EDGE CONNECTOR
SEQUENCER
RANDOM
PULSER
ENVELOPE
MOD
CMPLX
GATE
ART & ROW COPPER
Bourns 3266W footprints for fine tune
PROTOTYPING AREA

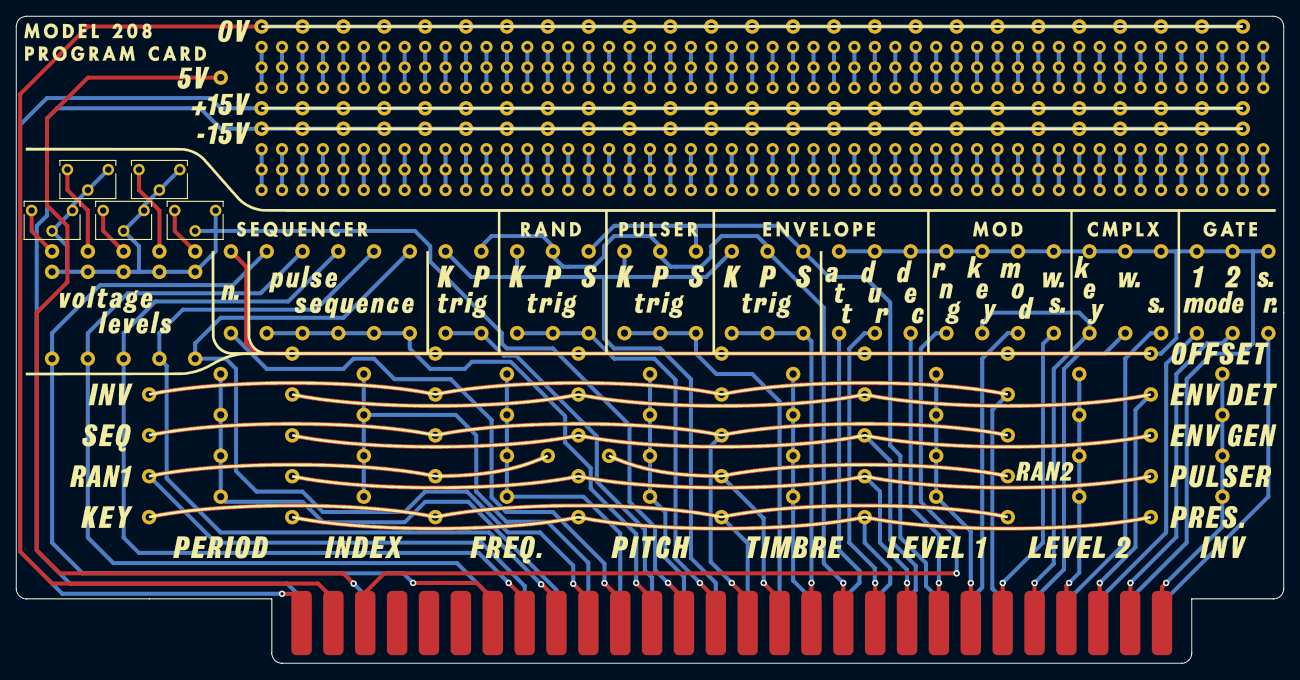
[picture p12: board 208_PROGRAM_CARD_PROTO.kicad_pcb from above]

Board: 2 copper layers, 157.5 x 80.4 mm, 332 parts (1 on the bottom side), 154 nets.
